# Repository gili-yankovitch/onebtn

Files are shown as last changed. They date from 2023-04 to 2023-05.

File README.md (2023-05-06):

# OneBtn
This is the OneBtn. A context-aware multi-purpose macro pad to control everything with  a push of a (single) button.

<p align="center">
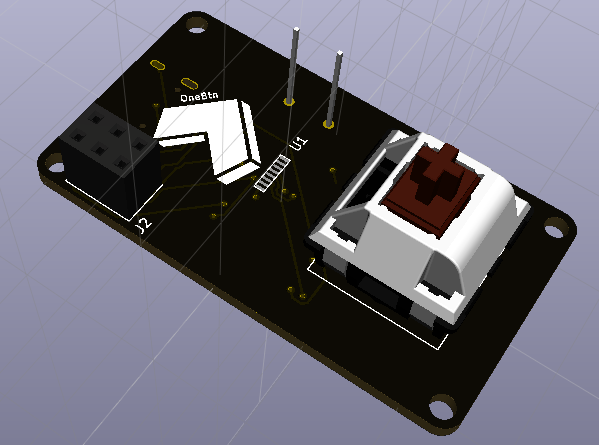
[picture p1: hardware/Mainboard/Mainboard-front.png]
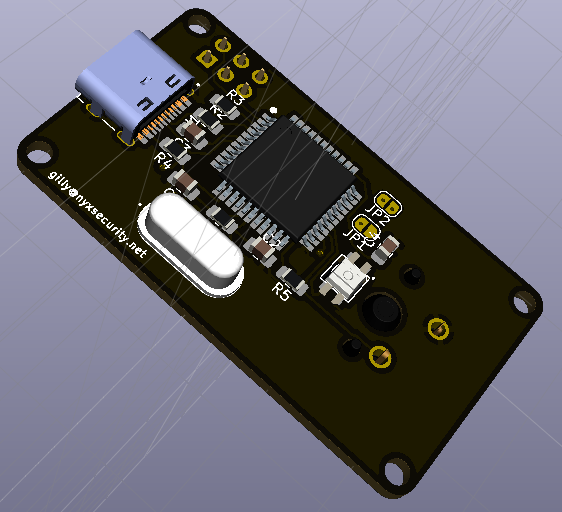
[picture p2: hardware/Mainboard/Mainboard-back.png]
   
</p>

## Prerequisits
### Software
Please install the following software to be able to flash software to the device:
* [Arduino SDK](https://www.arduino.cc/en/software)
* [Platformio](https://platformio.org/install/cli) or VScode with Platformio AddOn

### Hardware
All PCB specs are provided here under [hardware/](https://github.com/gili-yankovitch/onebtn/tree/master/hardware). This can be easily manufactured as well as paneled for a larger volume. There are no special requirements for this board's manufacturing process.

#### Bill of Materials
| Quantity | Component Description | Mfr. No | Datasheet |
|---|---|---|---|
| 2 | SMD 1/4W 22 OHM 1% | RK73H2ATTD22R0F | [Datasheet](https://www.mouser.co.il/datasheet/2/219/RK73H-1825326.pdf) |
| 1 | SMD 1 kOhms 125 mW 0805 5% | RC0805JR-071KL | [Datasheet](https://www.mouser.co.il/datasheet/2/447/PYu_RC_Group_51_RoHS_L_11-1984063.pdf) |
| 1 | SMD 1/4watts 10Kohms 5% | RK73B2ATTD103J | [Datasheet](https://www.mouser.co.il/datasheet/2/219/RK73B-1825463.pdf) |
| 1 | SMD 1M ohm 1% 50 ppm Thin Film | RT0805FRE101ML | [Datasheet](https://www.mouser.co.il/datasheet/2/447/PYu_RT_1_to_0_01_RoHS_L_12-3003070.pdf) |
| 1 | SMD/SMT 100V 20pF C0G 0805 5% | CC0805JRNPO0BN200 | [Datasheet](https://www.mouser.co.il/datasheet/2/447/UPY_NP0X7R_MV_100_to_630V_24-2604388.pdf) |
| 1 | SMD/SMT CAP ,MLCC ,0805,25V ,X7R,1.0UF20% ,T&R | MCAST21GSB7105MTNB25 | [Datasheet](https://www.mouser.co.il/datasheet/2/396/Taiyo_Yuden_1102023_MC_mlcc_all_e-3081584.pdf) |
| 1 | SMD/SMT 50V 0.1uF X7R 0805 10% | C0805C104K5RAC7411 | [Datasheet](https://www.mouser.co.il/datasheet/2/212/KEM_C1002_X7R_SMD-1102033.pdf) |
| 1 | Type C 16Pins SMT Socket Connector USB 3.1 Type-C Female MD DIP | [Link](https://www.aliexpress.com/item/4001076043694.html?spm=a2g0o.order_list.0.0.2e2f1802zEBigU) | [Datasheet](https://ae01.alicdn.com/kf/H1e697b3dd3c54072b04ede95a2d44105H.jpg) |
| 1 | 0.2W Intelligent external control surface mount SMD LED | SK6812Mini-E | [Datasheet](https://cdn-shop.adafruit.com/product-files/4960/4960_SK6812MINI-E_REV02_EN.pdf) |
| 1 | Crystals Crystals 16MHz 20pF | FOXSDLF/160-20 | [Datasheet](https://www.mouser.co.il/datasheet/2/3/C4SD-2141100.pdf) |
| 1 | 8-bit Microcontrollers - MCU 8-bit Microcontrollers - MCU AVR USB 32K FLASH | ATMEGA32U4-AU | [Datasheet](https://www.mouser.co.il/datasheet/2/268/Atmel_7766_8_bit_AVR_ATmega16U4_32U4_Datasheet-1315135.pdf) |
| 1 | OLED Display LCD 0.42" White LCD Screen Display Module | [Link](https://www.aliexpress.com/item/1005004674483621.html?spm=a2g0o.order_list.order_list_main.53.3f8418028cM6Vv) | [Datasheet](https://www.vishay.com/docs/37902/oled128o064dbpp3n00000.pdf) |
| 1 | Transparent Cover Key Keycaps Double-layer Custom Switch | [Link](https://www.aliexpress.com/item/1005002716375572.html?spm=a2g0o.order_list.order_list_main.137.3f8418028cM6Vv) |  |
| 1 | Outemu Switch Mechanical Keyboard Switch 3Pin | [Link](https://www.aliexpress.com/item/1005002378701948.html?spm=a2g0o.order_list.order_list_main.242.3f8418028cM6Vv) |  |

# Software
## Building
To build this project, usage of PlatformIO is recommended although the Arduino IDE will probably work as well. To use PlatformIO, simply run:
```
pio run --environment leonardo
```

## Flashing
This device accepts software in two ways: First through the ICSP port and the other through USB (after flashing Arduino Leonardo bootloader).

To flash using the ICSP port, simply use any Arduino device, flash it with the Arduino as ISP example from the Arduino IDE and use it to flash firmware to this device. While doing that, one might wish to use the Arduino IDE further by simply flashing the Arduino Bootloader to the device. Once this is done, USB flashing will be available. To flash the software using USB, simply run:
```
pio run --environment leonardo --target upload
```

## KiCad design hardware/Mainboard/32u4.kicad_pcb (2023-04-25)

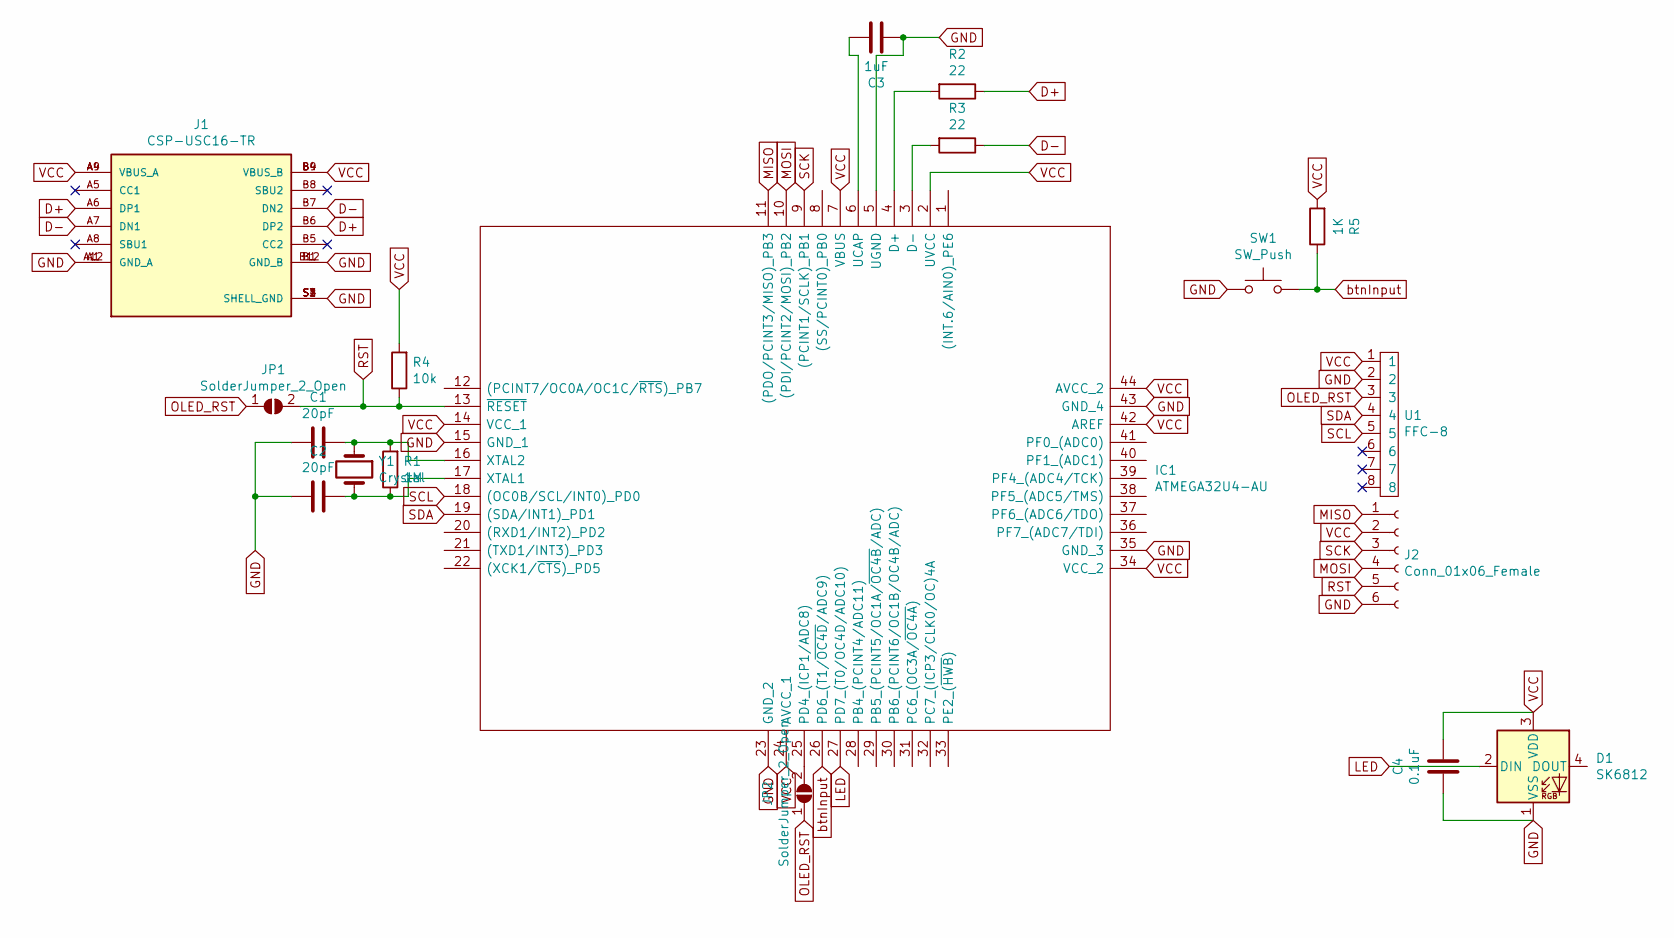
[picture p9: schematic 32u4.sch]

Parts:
C1, C2: 20pF; C_0805_2012Metric_Pad1.18x1.45mm_HandSolder
C3: 1uF; C_0805_2012Metric_Pad1.18x1.45mm_HandSolder
C4: 0.1uF; C_0805_2012Metric_Pad1.18x1.45mm_HandSolder
D1: SK6812; LED-3535
IC1: ATMEGA32U4-AU; QFP80P1200X1200X120-44N; Mouser Part Number 556-ATMEGA32U4-AU
J1: CSP-USC16-TR; VALCON_CSP-USC16-TR-Fixed; PARTREV A0
J2: Conn_01x06_Female; PinSocket_2x03_P2.54mm_Vertical
JP1, JP2: SolderJumper_2_Open; SolderJumper-2_P1.3mm_Open_RoundedPad1.0x1.5mm
R1: 1M; R_0805_2012Metric_Pad1.20x1.40mm_HandSolder
R2, R3: 22; R_0805_2012Metric_Pad1.20x1.40mm_HandSolder
R4: 10k; R_0805_2012Metric_Pad1.20x1.40mm_HandSolder
R5: 1K; R_0805_2012Metric_Pad1.20x1.40mm_HandSolder
SW1: SW_Push; SW_Cherry_MX_1.00u_PCB
U1: FFC-8; OLED-0.6Pitch-8Pins
Y1: Crystal; FOXSLF16020

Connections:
D+: J1.A6 (DP1), J1.B6 (DP2), R2.1
D-: J1.A7 (DN1), J1.B7 (DN2), R3.1
GND: C1.2, C2.2, C3.2, C4.2, D1.1 (VSS), IC1.5 (UGND), IC1.15 (GND_1), IC1.23 (GND_2), IC1.35 (GND_3), IC1.43 (GND_4), J1.A1 (GND_A), J1.A12 (GND_A), J1.B1 (GND_B), J1.B12 (GND_B), J1.S1 (SHELL_GND), J1.S2 (SHELL_GND), J1.S3 (SHELL_GND), J1.S4 (SHELL_GND), J2.6, SW1.1, U1.2
LED: D1.2 (DIN), IC1.27 (PD7_(T0/OC4D/ADC10))
MISO: IC1.11 ((PDO/PCINT3/MISO)_PB3), J2.1
MOSI: IC1.10 ((PDI/PCINT2/MOSI)_PB2), J2.4
unnamed: C1.1, IC1.16 (XTAL2), R1.2, Y1.1
unnamed: C2.1, IC1.17 (XTAL1), R1.1, Y1.2
unnamed: C3.1, IC1.6 (UCAP)
unnamed: IC1.3 (D-), R3.2
unnamed: IC1.4 (D+), R2.2
unnamed: IC1.25 (PD4_(ICP1/ADC8)), JP2.2 (B)
OLED_RST: JP1.1 (A), JP2.1 (A), U1.3
RST: IC1.13 (~RESET), J2.5, JP1.2 (B), R4.1
SCK: IC1.9 ((PCINT1/SCLK)_PB1), J2.3
SCL: IC1.18 ((OC0B/SCL/INT0)_PD0), U1.5
SDA: IC1.19 ((SDA/INT1)_PD1), U1.4
VCC: C4.1, D1.3 (VDD), IC1.2 (UVCC), IC1.7 (VBUS), IC1.14 (VCC_1), IC1.24 (AVCC_1), IC1.34 (VCC_2), IC1.42 (AREF), IC1.44 (AVCC_2), J1.A4 (VBUS_A), J1.A9 (VBUS_A), J1.B4 (VBUS_B), J1.B9 (VBUS_B), J2.2, R4.2, R5.2, U1.1
btnInput: IC1.26 (PD6_(T1/~OC4D~/ADC9)), R5.1, SW1.2

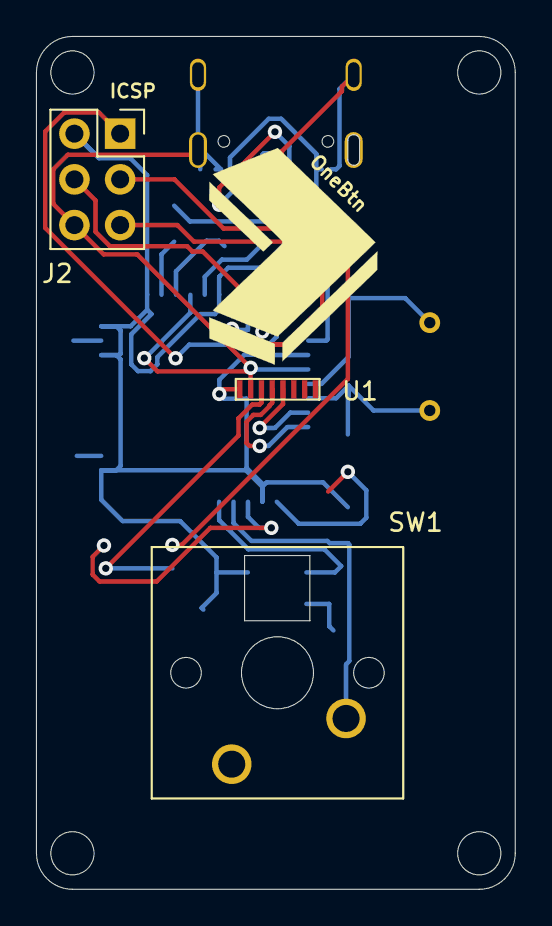
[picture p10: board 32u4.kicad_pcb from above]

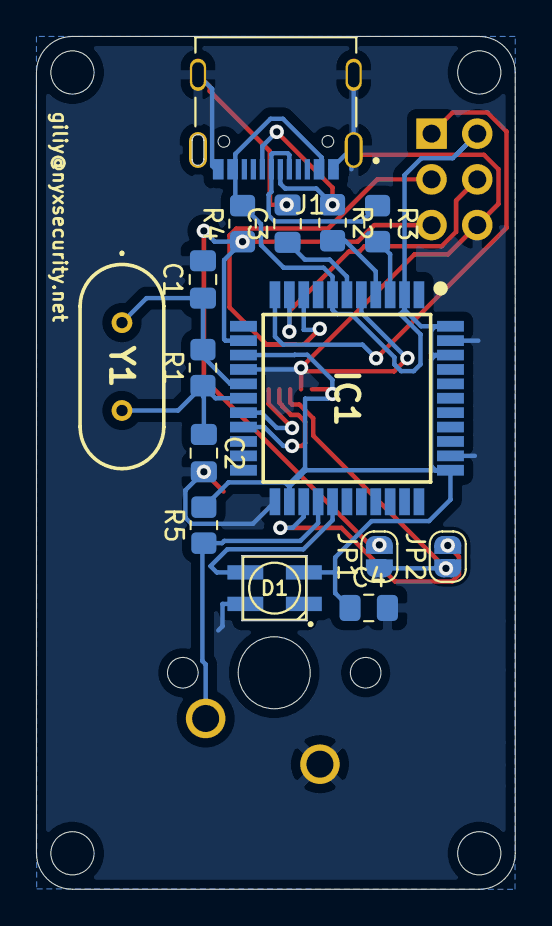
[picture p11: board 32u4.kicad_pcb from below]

Board: 2 copper layers, 26.6 x 47.4 mm, 18 parts (15 on the bottom side), 19 nets.

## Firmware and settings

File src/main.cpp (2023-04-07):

#include <Arduino.h>
#include <NeoPixelBus.h>
#include <SPI.h>
#include <Wire.h>
#include <Adafruit_GFX.h>
#include <Adafruit_SSD1306.h>
#include <Keyboard.h>

#define SCREEN_WIDTH 128    // OLED display width, in pixels
#define SCREEN_HEIGHT 64    // OLED display height, in pixels
#define SCREEN_ADDRESS 0x3c ///< See datasheet for Address; 0x3D for 128x64, 0x3C for 128x32

#define LED_PIN 6
#define BTN_PIN 12

NeoPixelBus<NeoGrbFeature, Neo800KbpsMethod>
    ledStrip(1, LED_PIN);

#define OLED_RESET -1 // Reset pin # (or -1 if sharing Arduino reset pin)

Adafruit_SSD1306 display(SCREEN_WIDTH, SCREEN_HEIGHT, &Wire, OLED_RESET);

#define LOGO_HEIGHT 16
#define LOGO_WIDTH 16

#define NUMFLAKES 5
#define XPOS 0 // Indexes into the 'icons' array in function below
#define YPOS 1
#define DELTAY 2

int8_t icons[NUMFLAKES][3];
int8_t animationIdx = 0;

#define FRAMES 6
static const unsigned char PROGMEM animation[6][512] = {{0b00000000, 0b00000000, 0b00000000, 0b00000000, 0b00000000, 0b00000000, 0b00000000, 0b00000000, 0b00000000, 0b00000000, 0b00000000, 0b00000000, 0b00000000, 0b00000000, 0b00000000, 0b00000000, 0b00000000, 0b00000000, 0b00000000, 0b00000000, 0b00000000, 0b00000000, 0b00000000, 0b00000000, 0b00000000, 0b00000000, 0b00000000, 0b00000000, 0b00000000, 0b00000000, 0b00000000, 0b00000000, 0b00000000, 0b00000000, 0b00000000, 0b00000000, 0b00000000, 0b00000000, 0b00000000, 0b00000000, 0b00000000, 0b00000000, 0b00000000, 0b00000000, 0b00000000, 0b00000000, 0b00000000, 0b00000000, 0b00000000, 0b00000000, 0b00000000, 0b00000000, 0b00000000, 0b00000000, 0b00000000, 0b00000000, 0b00000000, 0b00000000, 0b00000000, 0b00000000, 0b00000000, 0b00000000, 0b00000000, 0b00000000, 0b00000000, 0b00000000, 0b00000000, 0b00000000, 0b00000000, 0b00000000, 0b00000000, 0b00000000, 0b00000000, 0b00000000, 0b00000000, 0b00000000, 0b00000000, 0b00000000, 0b00000000, 0b00000000, 0b00000000, 0b00000000, 0b00000000, 0b00000000, 0b00000000, 0b00000000, 0b00000000, 0b00000000, 0b00000000, 0b00000000, 0b00000000, 0b00000000, 0b00000000, 0b00000000, 0b00000000, 0b00000000, 0b00000000, 0b00000000, 0b00000000, 0b00000000, 0b00000000, 0b00000000, 0b00000000, 0b00000000, 0b00000000, 0b00000000, 0b00000000, 0b00000000, 0b00000000, 0b00000000, 0b00000000, 0b00000000, 0b00000000, 0b00000000, 0b01111111, 0b11111111, 0b11111111, 0b11111111, 0b10000000, 0b00000000, 0b00000000, 0b00000000, 0b01111111, 0b11111111, 0b11111111, 0b11111111, 0b10000000, 0b00000000, 0b00000000, 0b00000000, 0b10000000, 0b00000000, 0b00000000, 0b00000000, 0b01000000, 0b00000000, 0b00000000, 0b00000011, 0b00000000, 0b00000000, 0b00000000, 0b00000000, 0b00110000, 0b00000000, 0b00000000, 0b00000011, 0b00000000, 0b00000000, 0b00000000, 0b00000000, 0b00110000, 0b00000000, 0b00000000, 0b00000011, 0b00000000, 0b00000011, 0b00001000, 0b00000000, 0b00110000, 0b00000000, 0b00000000, 0b00000011, 0b00000000, 0b00000011, 0b00001000, 0b00000000, 0b00110000, 0b00000000, 0b00000000, 0b00000011, 0b00000110, 0b00000000, 0b00000000, 0b00000000, 0b00110000, 0b00000000, 0b00000000, 0b00000011, 0b00000110, 0b00000000, 0b00000000, 0b00000000, 0b00110000, 0b00000000, 0b00000000, 0b00000011, 0b00000000, 0b00000000, 0b00001110, 0b00011000, 0b00110011, 0b11000000, 0b00000000, 0b00000011, 0b00000000, 0b00000000, 0b00001110, 0b00011000, 0b00110011, 0b11000000, 0b00000000, 0b00000011, 0b00000000, 0b00000000, 0b00110001, 0b10000000, 0b00111100, 0b00110000, 0b00000000, 0b00000011, 0b00000000, 0b00000000, 0b00110001, 0b10000000, 0b00111100, 0b00110000, 0b00011111, 0b11000011, 0b00000000, 0b00001100, 0b00110000, 0b01100000, 0b00110000, 0b00110000, 0b00010000, 0b11110011, 0b00000000, 0b00000000, 0b00110000, 0b00011111, 0b11000000, 0b00110000, 0b00010000, 0b11110011, 0b00000000, 0b00000000, 0b00110000, 0b00011111, 0b11000000, 0b00110000, 0b00011100, 0b00111111, 0b00000001, 0b10000000, 0b00110000, 0b00000000, 0b00000000, 0b00110000, 0b00011100, 0b00111111, 0b00000001, 0b10000000, 0b00110000, 0b00000000, 0b00000000, 0b00110000, 0b00001111, 0b00001111, 0b00000000, 0b00000011, 0b11000000, 0b00000000, 0b00000000, 0b00001000, 0b00001111, 0b00001111, 0b00000000, 0b00000011, 0b11000000, 0b00000000, 0b00000000, 0b00001000, 0b00000011, 0b11000011, 0b00011000, 0b00000000, 0b11000000, 0b01100000, 0b00000011, 0b00001000, 0b00000011, 0b11000011, 0b00011000, 0b00000000, 0b11000000, 0b01100000, 0b00000011, 0b00001000, 0b00000000, 0b11111111, 0b00000000, 0b00000000, 0b11000001, 0b11100000, 0b01001111, 0b00001000, 0b00000000, 0b00001111, 0b00000000, 0b00010000, 0b11001110, 0b00000000, 0b00000000, 0b11111000, 0b00000000, 0b00001111, 0b00000000, 0b00010000, 0b11001110, 0b00000000, 0b00000000, 0b11111000, 0b00000000, 0b00000011, 0b00000110, 0b00000000, 0b11001110, 0b01100001, 0b10001100, 0b11111000, 0b00000000, 0b00000011, 0b00000110, 0b00000000, 0b11001110, 0b01100001, 0b10001100, 0b11111000, 0b00000000, 0b00000011, 0b00000000, 0b00000000, 0b00110000, 0b01111111, 0b11111100, 0b00110000, 0b00000000, 0b00000011, 0b00000000, 0b00000000, 0b00110000, 0b01111111, 0b11111100, 0b00110000, 0b00000000, 0b00001111, 0b10000000, 0b00000000, 0b00001000, 0b00000000, 0b00000000, 0b11000000, 0b00000000, 0b00001111, 0b10000000, 0b00000000, 0b00001000, 0b00000000, 0b00000000, 0b11000000, 0b00000000, 0b00110000, 0b01111111, 0b11111111, 0b11111111, 0b11111111, 0b11111111, 0b00000000, 0b00000000, 0b00110000, 0b01111111, 0b11111111, 0b11111111, 0b11111111, 0b11111111, 0b00000000, 0b00000000, 0b00110000, 0b11100110, 0b00010000, 0b00000110, 0b00011001, 0b10001100, 0b00000000, 0b00000000, 0b00110000, 0b11100110, 0b00010000, 0b00000110, 0b00011001, 0b10001100, 0b00000000, 0b00000000, 0b00111111, 0b10000111, 0b11100000, 0b00000001, 0b11111000, 0b01110000, 0b00000000, 0b00000000, 0b00000000, 0b00000000, 0b00000000, 0b00000000, 0b00000000, 0b00000000, 0b00000000, 0b00000000, 0b00000000, 0b00000000, 0b00000000, 0b00000000, 0b00000000, 0b00000000, 0b00000000, 0b00000000, 0b00000000, 0b00000000, 0b00000000, 0b00000000, 0b00000000, 0b00000000, 0b00000000, 0b00000000, 0b00000000, 0b00000000, 0b00000000, 0b00000000, 0b00000000, 0b00000000, 0b00000000, 0b00000000, 0b00000000, 0b00000000, 0b00000000, 0b00000000, 0b00000000, 0b00000000, 0b00000000, 0b00000000, 0b00000000, 0b00000000, 0b00000000, 0b00000000, 0b00000000, 0b00000000, 0b00000000, 0b00000000, 0b00000000, 0b00000000, 0b00000000, 0b00000000, 0b00000000, 0b00000000, 0b00000000, 0b00000000, 0b00000000, 0b00000000, 0b00000000, 0b00000000, 0b00000000, 0b00000000, 0b00000000, 0b00000000, 0b00000000, 0b00000000, 0b00000000, 0b00000000, 0b00000000, 0b00000000, 0b00000000, 0b00000000, 0b00000000, 0b00000000, 0b00000000, 0b00000000, 0b00000000, 0b00000000, 0b00000000, 0b00000000, 0b00000000, 0b00000000, 0b00000000, 0b00000000, 0b00000000, 0b00000000, 0b00000000, 0b00000000, 0b00000000, 0b00000000, 0b00000000, 0b00000000, 0b00000000, 0b00000000, 0b00000000, 0b00000000, 0b00000000, 0b00000000, 0b00000000, 0b00000000, 0b00000000, 0b00000000, 0b00000000, 0b00000000, 0b00000000, 0b00000000, 0b00000000, 0b00000000, 0b00000000, 0b00000000, 0b00000000}, {0b00000000, 0b00000000, 0b00000000, 0b00000000, 0b00000000, 0b00000000, 0b00000000, 0b00000000, 0b00000000, 0b00000000, 0b00000000, 0b00000000, 0b00000000, 0b00000000, 0b00000000, 0b00000000, 0b00000000, 0b00000000, 0b00000000, 0b00000000, 0b00000000, 0b00000000, 0b00000000, 0b00000000, 0b00000000, 0b00000000, 0b00000000, 0b00000000, 0b00000000, 0b00000000, 0b00000000, 0b00000000, 0b00000000, 0b00000000, 0b00000000, 0b00000000, 0b00000000, 0b00000000, 0b00000000, 0b00000000, 0b00000000, 0b00000000, 0b00000000, 0b00000000, 0b00000000, 0b00000000, 0b00000000, 0b00000000, 0b00000000, 0b00000000, 0b00000000, 0b00000000, 0b00000000, 0b00000000, 0b00000000, 0b00000000, 0b00000000, 0b00000000, 0b00000000, 0b00000000, 0b00000000, 0b00000000, 0b00000000, 0b00000000, 0b00000000, 0b00000000, 0b00000000, 0b00000000, 0b00000000, 0b00000000, 0b00000000, 0b00000000, 0b00000000, 0b00000000, 0b00000000, 0b00000000, 0b00000000, 0b00000000, 0b00000000, 0b00000000, 0b00000000, 0b00000000, 0b00000000, 0b00000000, 0b00000000, 0b00000000, 0b00000000, 0b00000000, 0b00000000, 0b00000000, 0b00000000, 0b00000000, 0b00000000, 0b00000000, 0b00000000, 0b00000000, 0b00000000, 0b00000000, 0b00000000, 0b00000000, 0b00000000, 0b00000000, 0b00000000, 0b00000000, 0b00000000, 0b00000000, 0b00000000, 0b00000000, 0b00000000, 0b00000000, 0b00000000, 0b00000000, 0b00000000, 0b00000000, 0b00000000, 0b00000000, 0b00000000, 0b00000000, 0b00000000, 0b00000000, 0b00000000, 0b00000000, 0b00001000, 0b10001000, 0b10001000, 0b10001000, 0b00000000, 0b00000000, 0b00000000, 0b00000000, 0b01111111, 0b11111111, 0b11111111, 0b11111111, 0b10000000, 0b00000000, 0b00000000, 0b00000000, 0b01010101, 0b01010101, 0b01010101, 0b01010101, 0b01000000, 0b00000000, 0b00000000, 0b00000000, 0b10000000, 0b00000000, 0b00000000, 0b00000000, 0b01000000, 0b00000000, 0b00000000, 0b00000011, 0b00000000, 0b00000000, 0b00000000, 0b00000000, 0b00110000, 0b00000000, 0b00000000, 0b00000011, 0b00000000, 0b00000000, 0b00000000, 0b00000000, 0b00110000, 0b00000000, 0b00000000, 0b00000011, 0b00000000, 0b00000011, 0b00001000, 0b00000000, 0b00110000, 0b00000000, 0b00000000, 0b00000011, 0b00000000, 0b00000011, 0b00001100, 0b00000000, 0b00110000, 0b00000000, 0b00000000, 0b00000011, 0b00000110, 0b00000000, 0b00000000, 0b00000000, 0b00110000, 0b00000000, 0b00000000, 0b00000011, 0b00000110, 0b00000000, 0b00000001, 0b00000000, 0b00110000, 0b01000000, 0b00000000, 0b00000011, 0b00000000, 0b00000000, 0b00000111, 0b10011000, 0b00110001, 0b11110000, 0b00000000, 0b00000011, 0b00000000, 0b00000000, 0b00001010, 0b11010000, 0b00110001, 0b01010000, 0b00000000, 0b00000011, 0b00000000, 0b00000000, 0b00001000, 0b01100000, 0b00110011, 0b00001100, 0b00000000, 0b00000011, 0b00000000, 0b00000100, 0b00001100, 0b00101000, 0b00111010, 0b00011000, 0b00000000, 0b00000011, 0b00000000, 0b00001100, 0b00001000, 0b00011000, 0b00111100, 0b00001000, 0b00000000, 0b00000011, 0b00000000, 0b00000000, 0b00001100, 0b00000111, 0b11110000, 0b00011100, 0b00000000, 0b00000011, 0b00000000, 0b00000000, 0b00001000, 0b00000111, 0b11110000, 0b00001000, 0b00000000, 0b00000011, 0b00000001, 0b10000000, 0b00001100, 0b00000000, 0b00000000, 0b00011000, 0b00000000, 0b00000110, 0b00000001, 0b00000000, 0b00011000, 0b00000000, 0b00000000, 0b00001100, 0b00000000, 0b00001111, 0b00000000, 0b00000011, 0b00110000, 0b00000000, 0b00000000, 0b00000110, 0b00000000, 0b00001111, 0b00000000, 0b00000011, 0b00110000, 0b00000000, 0b00000000, 0b00000010, 0b00000011, 0b11111110, 0b00011000, 0b00000000, 0b00110000, 0b00011000, 0b00000000, 0b11000110, 0b00010101, 0b01010111, 0b00011000, 0b00000000, 0b00110000, 0b00111000, 0b00010011, 0b10000110, 0b00011100, 0b00000011, 0b00000000, 0b00000000, 0b00110000, 0b01111000, 0b00110011, 0b11000010, 0b00011000, 0b00101110, 0b00000000, 0b00010000, 0b00110011, 0b10000000, 0b00000000, 0b01011110, 0b00011000, 0b00111111, 0b00000000, 0b00111000, 0b00110111, 0b10000000, 0b00000000, 0b00111110, 0b00000111, 0b11110011, 0b00000110, 0b00000000, 0b00110011, 0b10011000, 0b01000011, 0b01111110, 0b00000111, 0b11110011, 0b00000110, 0b00000000, 0b00110111, 0b10011000, 0b11010011, 0b00111110, 0b00000000, 0b00000011, 0b00000000, 0b00000000, 0b00001000, 0b00011111, 0b11111111, 0b00001000, 0b00000000, 0b00000011, 0b00000000, 0b00000000, 0b00001100, 0b00011111, 0b11111110, 0b00011000, 0b00000000, 0b00000111, 0b10000000, 0b00000000, 0b00000010, 0b00000000, 0b00000000, 0b01100000, 0b00000000, 0b00000011, 0b10010001, 0b00001000, 0b10010111, 0b01000001, 0b00000001, 0b00100000, 0b00000000, 0b00000011, 0b01111111, 0b11111111, 0b11111111, 0b11111111, 0b11111111, 0b11000000, 0b00000000, 0b00000011, 0b00111101, 0b11011110, 0b11011010, 0b11110111, 0b11111011, 0b10000000, 0b00000000, 0b00000011, 0b00011001, 0b10000100, 0b00000000, 0b01100001, 0b00110000, 0b11000000, 0b00000000, 0b00000111, 0b11100000, 0b01111100, 0b00000000, 0b00011111, 0b10001111, 0b10000000, 0b00000000, 0b00000011, 0b11100000, 0b11111100, 0b00000000, 0b00011111, 0b00001111, 0b11000000, 0b00000000, 0b00000000, 0b00000000, 0b00000000, 0b00000000, 0b00000000, 0b00000000, 0b00000000, 0b00000000, 0b00000000, 0b00000000, 0b00000000, 0b00000000, 0b00000000, 0b00000000, 0b00000000, 0b00000000, 0b00000000, 0b00000000, 0b00000000, 0b00000000, 0b00000000, 0b00000000, 0b00000000, 0b00000000, 0b00000000, 0b00000000, 0b00000000, 0b00000000, 0b00000000, 0b00000000, 0b00000000, 0b00000000, 0b00000000, 0b00000000, 0b00000000, 0b00000000, 0b00000000, 0b00000000, 0b00000000, 0b00000000, 0b00000000, 0b00000000, 0b00000000, 0b00000000, 0b00000000, 0b00000000, 0b00000000, 0b00000000, 0b00000000, 0b00000000, 0b00000000, 0b00000000, 0b00000000, 0b00000000, 0b00000000, 0b00000000, 0b00000000, 0b00000000, 0b00000000, 0b00000000, 0b00000000, 0b00000000, 0b00000000, 0b00000000, 0b00000000, 0b00000000, 0b00000000, 0b00000000, 0b00000000, 0b00000000, 0b00000000, 0b00000000, 0b00000000, 0b00000000, 0b00000000, 0b00000000, 0b00000000, 0b00000000, 0b00000000, 0b00000000, 0b00000000, 0b00000000, 0b00000000, 0b00000000, 0b00000000, 0b00000000, 0b00000000, 0b00000000, 0b00000000, 0b00000000, 0b00000000, 0b00000000, 0b00000000, 0b00000000, 0b00000000}, {0b00000000, 0b00000000, 0b00000000, 0b00000000, 0b00000000, 0b00000000, 0b00000000, 0b00000000, 0b00000000, 0b00000000, 0b00000000, 0b00000000, 0b00000000, 0b00000000, 0b00000000, 0b00000000, 0b00000000, 0b00000000, 0b00000000, 0b00000000, 0b00000000, 0b00000000, 0b00000000, 0b00000000, 0b00000000, 0b00000000, 0b00000000, 0b00000000, 0b00000000, 0b00000000, 0b00000000, 0b00000000, 0b00000000, 0b00000000, 0b00000000, 0b00000000, 0b00000000, 0b00000000, 0b00000000, 0b00000000, 0b00000000, 0b00000000, 0b00000000, 0b00000000, 0b00000000, 0b00000000, 0b00000000, 0b00000000, 0b00000000, 0b00000000, 0b00000000, 0b00000000, 0b00000000, 0b00000000, 0b00000000, 0b00000000, 0b00000000, 0b00000000, 0b00000000, 0b00000000, 0b00000000, 0b00000000, 0b00000000, 0b00000000, 0b00000000, 0b00000000, 0b00000000, 0b00000000, 0b00000000, 0b00000000, 0b00000000, 0b00000000, 0b00000000, 0b00000000, 0b00000000, 0b00000000, 0b00000000, 0b00000000, 0b00000000, 0b00000000, 0b00000000, 0b00000000, 0b00000000, 0b00000000, 0b00000000, 0b00000000, 0b00000000, 0b00000000, 0b00000000, 0b00000000, 0b00000000, 0b00000000, 0b00000000, 0b00000000, 0b00000000, 0b00000000, 0b00000000, 0b00000000, 0b00000000, 0b00000000, 0b00000000, 0b00000000, 0b00000000, 0b00000000, 0b00000000, 0b00000000, 0b00000000, 0b00000000, 0b00000000, 0b00000000, 0b00000000, 0b00000000, 0b00000000, 0b00000000, 0b00000000, 0b00000000, 0b00000000, 0b00000000, 0b00000000, 0b00000000, 0b00000000, 0b00000000, 0b00001000, 0b10001000, 0b10001000, 0b10001000, 0b00000000, 0b00000000, 0b00000000, 0b00000000, 0b01111111, 0b11111111, 0b11111111, 0b11111111, 0b10000000, 0b00000000, 0b00000000, 0b00000000, 0b01010101, 0b01010101, 0b01010101, 0b01010101, 0b01000000, 0b00000000, 0b00000000, 0b00000000, 0b10000000, 0b00000000, 0b00000000, 0b00000000, 0b01000000, 0b00000000, 0b00000000, 0b00000011, 0b00000000, 0b00000000, 0b00000000, 0b00000000, 0b00110000, 0b00000000, 0b00000000, 0b00000011, 0b00000000, 0b00000000, 0b00000000, 0b00000000, 0b00110000, 0b00000000, 0b00000000, 0b00000011, 0b00000000, 0b00000011, 0b00001000, 0b00000000, 0b00110000, 0b00000000, 0b00000000, 0b00000011, 0b00000000, 0b00000011, 0b00001100, 0b00000000, 0b00110000, 0b00000000, 0b00000000, 0b00000011, 0b00000110, 0b00000000, 0b00000000, 0b00000000, 0b00110000, 0b00000000, 0b00000000, 0b00000011, 0b00000110, 0b00000000, 0b00000100, 0b00000000, 0b00110001, 0b00000000, 0b00000000, 0b00000011, 0b00000000, 0b00000000, 0b00011110, 0b00011000, 0b00110011, 0b11000000, 0b00000000, 0b00000011, 0b00000000, 0b00000000, 0b00101011, 0b00010000, 0b00110101, 0b01000000, 0b00000000, 0b00000011, 0b00000000, 0b00000000, 0b00100001, 0b11000000, 0b00111100, 0b00110000, 0b00000000, 0b00000011, 0b00000000, 0b00000100, 0b00110000, 0b01100000, 0b00110000, 0b01100000, 0b00000000, 0b00000011, 0b00000000, 0b00001100, 0b00100000, 0b01100000, 0b00110000, 0b00110000, 0b00011111, 0b11000011, 0b00000000, 0b00000000, 0b00110000, 0b00011111, 0b11000000, 0b01100000, 0b00011111, 0b11000110, 0b00000000, 0b00000000, 0b00100000, 0b00011111, 0b11000000, 0b00110000, 0b01100000, 0b11111111, 0b00000001, 0b10000000, 0b00110000, 0b00000000, 0b00000000, 0b01100000, 0b01100000, 0b01011111, 0b00000001, 0b00000000, 0b00100000, 0b00000000, 0b00000000, 0b00110000, 0b01111000, 0b00001110, 0b00000000, 0b00000011, 0b11000000, 0b00000000, 0b00000000, 0b00001000, 0b01010101, 0b01010111, 0b00000000, 0b00000011, 0b11000000, 0b00100000, 0b00000010, 0b00011000, 0b00001111, 0b11110011, 0b00011000, 0b00000000, 0b11000000, 0b01100000, 0b00000011, 0b00001000, 0b00000001, 0b01110110, 0b00011000, 0b00000000, 0b11000000, 0b11100000, 0b01001011, 0b00011000, 0b00000000, 0b00111111, 0b00000000, 0b00000000, 0b11000001, 0b11100000, 0b11001111, 0b00001000, 0b00000000, 0b00000111, 0b00000000, 0b00010000, 0b11001110, 0b00000000, 0b00000001, 0b01111000, 0b00000000, 0b00000010, 0b00000000, 0b00111000, 0b11011110, 0b00000000, 0b00000000, 0b11111000, 0b00000000, 0b00000011, 0b00000110, 0b00000000, 0b11001110, 0b01100001, 0b00001101, 0b11111000, 0b00000000, 0b00000111, 0b00000110, 0b00000000, 0b11011110, 0b01100011, 0b10001100, 0b11111000, 0b00000000, 0b00001110, 0b00000000, 0b00000000, 0b00100000, 0b01111111, 0b11111100, 0b00100000, 0b00000000, 0b00011111, 0b00000000, 0b00000000, 0b00110000, 0b01111111, 0b11111100, 0b01100000, 0b00000000, 0b00111111, 0b10000000, 0b00000000, 0b00001000, 0b00000000, 0b00000000, 0b10000000, 0b00000000, 0b00101101, 0b11001000, 0b10001000, 0b01011100, 0b10000000, 0b00100010, 0b11000000, 0b00000000, 0b11000000, 0b11111111, 0b11111111, 0b11111111, 0b11111111, 0b11111111, 0b00000000, 0b00000000, 0b11000010, 0b11110111, 0b11011011, 0b01011110, 0b11111111, 0b00110000, 0b00000000, 0b00000000, 0b11000011, 0b01100001, 0b00000000, 0b00001000, 0b01100100, 0b00110000, 0b00000000, 0b00000000, 0b01111100, 0b00011111, 0b10000000, 0b00000111, 0b11100011, 0b11110000, 0b00000000, 0b00000000, 0b11111100, 0b00011111, 0b00000000, 0b00000111, 0b11100001, 0b11110000, 0b00000000, 0b00000000, 0b00000000, 0b00000000, 0b00000000, 0b00000000, 0b00000000, 0b00000000, 0b00000000, 0b00000000, 0b00000000, 0b00000000, 0b00000000, 0b00000000, 0b00000000, 0b00000000, 0b00000000, 0b00000000, 0b00000000, 0b00000000, 0b00000000, 0b00000000, 0b00000000, 0b00000000, 0b00000000, 0b00000000, 0b00000000, 0b00000000, 0b00000000, 0b00000000, 0b00000000, 0b00000000, 0b00000000, 0b00000000, 0b00000000, 0b00000000, 0b00000000, 0b00000000, 0b00000000, 0b00000000, 0b00000000, 0b00000000, 0b00000000, 0b00000000, 0b00000000, 0b00000000, 0b00000000, 0b00000000, 0b00000000, 0b00000000, 0b00000000, 0b00000000, 0b00000000, 0b00000000, 0b00000000, 0b00000000, 0b00000000, 0b00000000, 0b00000000, 0b00000000, 0b00000000, 0b00000000, 0b00000000, 0b00000000, 0b00000000, 0b00000000, 0b00000000, 0b00000000, 0b00000000, 0b00000000, 0b00000000, 0b00000000, 0b00000000, 0b00000000, 0b00000000, 0b00000000, 0b00000000, 0b00000000, 0b00000000, 0b00000000, 0b00000000, 0b00000000, 0b00000000, 0b00000000, 0b00000000, 0b00000000, 0b00000000, 0b00000000, 0b00000000, 0b00000000, 0b00000000, 0b00000000, 0b00000000, 0b00000000, 0b00000000, 0b00000000, 0b00000000}, {0b00000000, 0b00000000, 0b00000000, 0b00000000, 0b00000000, 0b00000000, 0b00000000, 0b00000000, 0b00000000, 0b00000000, 0b00000000, 0b00000000, 0b00000000, 0b00000000, 0b00000000, 0b00000000, 0b00000000, 0b00000000, 0b00000000, 0b00000000, 0b00000000, 0b00000000, 0b00000000, 0b00000000, 0b00000000, 0b00000000, 0b00000000, 0b00000000, 0b00000000, 0b00000000, 0b00000000, 0b00000000, 0b00000000, 0b00000000, 0b00000000, 0b00000000, 0b00000000, 0b00000000, 0b00000000, 0b00000000, 0b00000000, 0b00000000, 0b00000000, 0b00000000, 0b00000000, 0b00000000, 0b00000000, 0b00000000, 0b00000000, 0b00000000, 0b00000000, 0b00000000, 0b00000000, 0b00000000, 0b00000000, 0b00000000, 0b00000000, 0b00000000, 0b00000000, 0b00000000, 0b00000000, 0b00000000, 0b00000000, 0b00000000, 0b00000000, 0b00000000, 0b00000000, 0b00000000, 0b00000000, 0b00000000, 0b00000000, 0b00000000, 0b00000000, 0b00000000, 0b00000000, 0b00000000, 0b00000000, 0b00000000, 0b00000000, 0b00000000, 0b00000000, 0b00000000, 0b00000000, 0b00000000, 0b00000000, 0b00000000, 0b00000000, 0b00000000, 0b00000000, 0b00000000, 0b00000000, 0b00000000, 0b00000000, 0b00000000, 0b00000000, 0b00000000, 0b00000000, 0b00000000, 0b00000000, 0b00000000, 0b00000000, 0b00000000, 0b00000000, 0b00000000, 0b00000000, 0b00000000, 0b00000000, 0b00000000, 0b00000000, 0b00000000, 0b00000000, 0b00000000, 0b00000000, 0b00000000, 0b01111111, 0b11111111, 0b11111111, 0b11111111, 0b10000000, 0b00000000, 0b00000000, 0b00000000, 0b00110111, 0b01110111, 0b01110111, 0b01110110, 0b10000000,
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
void loop()
{
  static uint8_t delayCtr = 0;

  // Configuration logic
  if (Serial.available())
  {
    handleConfig();
  }

  // Button press logic
  if (digitalRead(BTN_PIN) == 1)
  {
    ledStrip.SetPixelColor(0, RgbColor(128, 128, 128));
    ledStrip.Show();
  }
  else
  {
    int i;
    ledStrip.SetPixelColor(0, RgbColor(0, 255, 0));
    ledStrip.Show();

    if (keys.keys)
    {
      // Press all keys
      for (i = 0; i < keys.n; ++i)
      {
        Keyboard.press(keys.keys[i]);
        delay(10);
      }

      Keyboard.releaseAll();

      delay(200);
    }
  }

  if (delayCtr++ % 4 == 0)
  {
    // Loop forever...
    display.clearDisplay(); // Clear the display buffer

    if (img.data != NULL)
    {
      display.drawBitmap(img.x, img.y + (animationIdx % 2) * 5, img.data, img.width, img.height, SSD1306_WHITE);
    }
    else
    {
      display.drawBitmap(30, -15, animation[animationIdx], 64, 64, SSD1306_WHITE);
    }

    animationIdx = (animationIdx + 1) % FRAMES;

    display.display(); // Show the display buffer on the screen
  }

  delay(50); // Pause for a while
}

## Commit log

2023-04-06 WIP automatic window detection + key switching
2023-04-25 Adding hardware source files
    [32u4.kicad_pcb, 32u4.sch, TinyOLED.kicad_pcb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]
